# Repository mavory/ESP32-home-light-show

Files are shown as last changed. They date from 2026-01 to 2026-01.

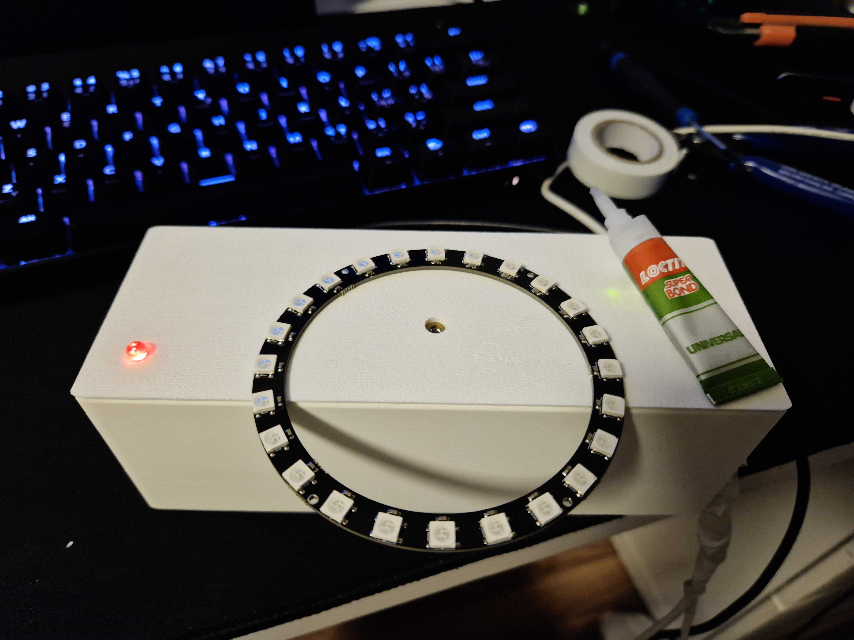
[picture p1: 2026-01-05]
Photos/IMG_20260105_200620.jpg

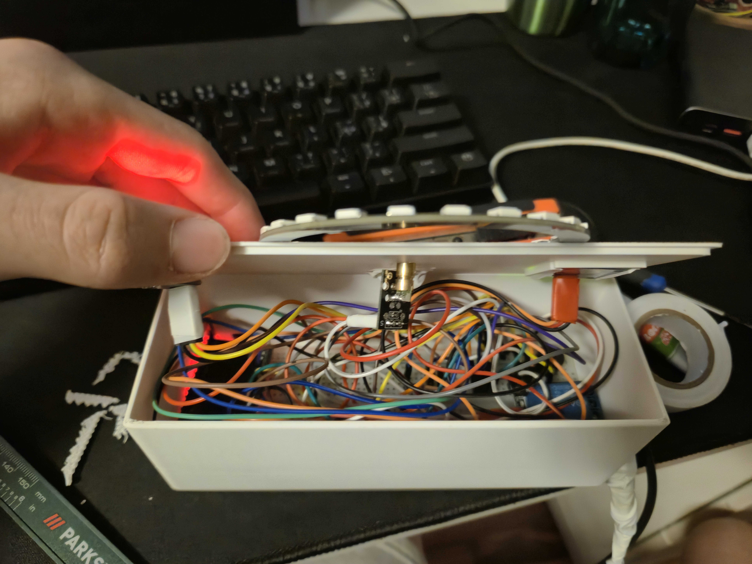
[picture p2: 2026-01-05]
Photos/20260105_195151.jpg

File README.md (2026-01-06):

# ESP32 home light show

Using ESP32 you can make a small home light show with 2 LED strips, a neopixel ring, a laser, a buzzer and an RGB LED!

## Why did I do this?

I wanted to create something with lighting effects and a few days ago I got this ring, so I wanted to try it out and also see how the relay works with LED strips.

## Features

- Web interface
- You can switch modes
- It has a buzzer and an RGB LED for notification
- You can turn off various lights, buzzer, etc.

## Scripts

The script has exactly 199 lines, so it fit under 200!! It was very difficult, but I put everything in just one script, so you can just copy it and paste it into the ESP32 right away.

## How it works?

You can change profiles and turn off various lights via the web. The web runs on the ESP32 IP address. There is a small RGB LED and a buzzer for signaling. Everything can be turned on manually using the touch sensor hidden in the case.

- **Mode 1 (FOREST):** Constant green ring light with strip.
- **Mode 2 (CYBER):** Constant magenta ring light with laser.
- **Mode 3 (NUCLEAR):** Blinking relay with orange ring and pulsing warning buzzer.
- **Mode 4 (SUNSET):** Breathing effect on the ring in sunset colors.
- **Mode 5 (AMBIENT):** White ring light and relay for steady "illumination".
- **Mode 6 (FOCUS):** Blue pulsing ring effect for concentration with active relay.
- **Mode 7 (DISCO):** Strobe for relay and laser with rainbow ring and rhythmic beeps.
- **Mode 8 (STROBE):** High speed white strobe and ring with buzzer.
- **Mode 9 (POLICE):** Red and blue flashing ring with a siren sound.
- **Mode 10 (EXTREME):** Random chaotic flashing with flickering colors and noise.

**_I like sunset the most and extreme is probably the most chaotic!_**

### Home page:


## 3D models

Here is a view of the top and bottom of the case:





# Wiring Diagram



### Components:
- **ESP32** (Powered via USB or 5V Vin)
- **Touch Sensor (TTP223):**
  - SIG: GPIO 4
  - VCC: 3.3V / 5V
  - GND: GND

### Outputs:
- **Relay (Strip Control):** GPIO 23
- **Laser Diode:** GPIO 22
- **Passive Buzzer:** GPIO 17

### Lights:
- **NeoPixel Ring (24 LEDs):**
  - Data: GPIO 21
  - VCC: 5V 
  - GND: GND
- **RGB LED:**
  - Red Pin: GPIO 19
  - Green Pin: GPIO 18
  - Blue Pin: GPIO 5
  - GND: GND
- **LED strips:**
  - 5V: COM (Relay) ---> 5V external (NO on relay)
  - GND: GND
  
# Libraries:

```
- Arduino.h
- WiFi.h
- ESPAsyncWebServer.h 
- AsyncTCP.h
- Adafruit_NeoPixel.h
- LittleFS.h
```

## There is the final video of how it works!

_Here is a youtube video where you can see how it works:_ [Link](https://www.youtube.com/watch?v=FMIBLFgBRWg)



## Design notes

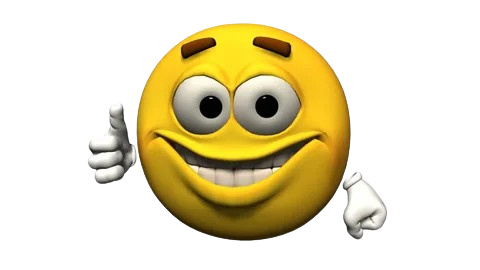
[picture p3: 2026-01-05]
Photos/1-removebg-preview.png

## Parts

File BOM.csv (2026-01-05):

Item | Quantity | Link
ESP32 | 1 | https://www.aliexpress.com/item/1005009694232832.html?curPageLogUid=bPYYmnweQOZ8
RGB led | 1 | https://www.aliexpress.com/item/32977462875.html?scm_id=1007.40050.354490.0&scm-url=1007.40050.354490.0
Touch sensor | 1 | https://www.aliexpress.com/item/1005008974368078.html?curPageLogUid=BUF3rwzADrHK
Breadboard | 1 | https://www.aliexpress.com/item/1005009799908389.html
Laser module | 1 | https://www.aliexpress.com/item/1005002823239061.html
Buzzer | 1 | https://www.aliexpress.com/item/1005006260328559.html?curPageLogUid=u9zf8d5xh8uM
Jumpers | Much | https://www.aliexpress.com/item/1005002611994443.html?curPageLogUid=fx2zB0EGcu5H
Led strips | 2 | https://www.aliexpress.com/item/1005009927754396.html?curPageLogUid=CeXHUmpYYu8P
Rele | 1 | https://www.aliexpress.com/item/1005009119776598.html?curPageLogUid=jzKWMm1aqF48
Ring module | 1 | https://www.aliexpress.com/item/1005008125328620.html

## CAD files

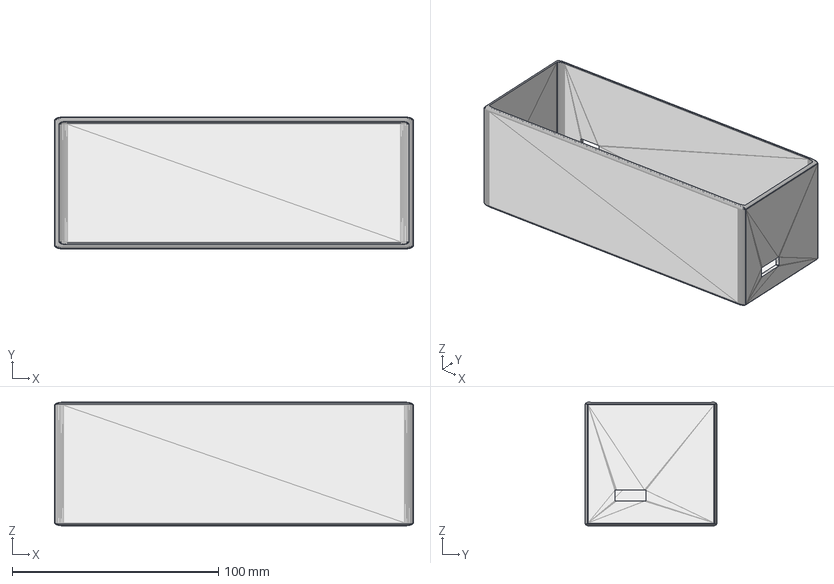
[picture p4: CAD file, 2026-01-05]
CAD/Case_bottom.step
174.0 x 64.0 x 60.0 mm

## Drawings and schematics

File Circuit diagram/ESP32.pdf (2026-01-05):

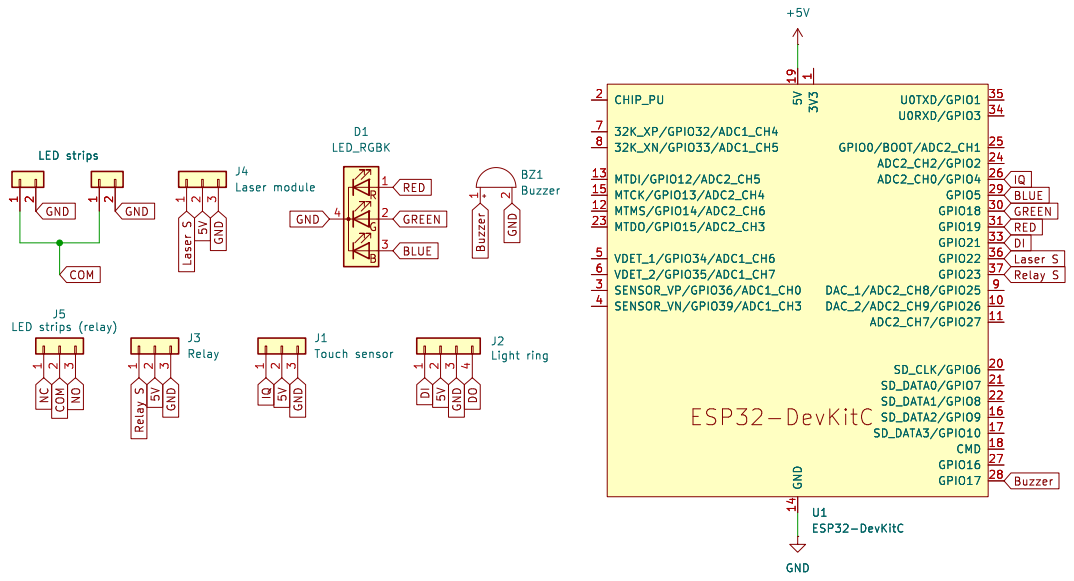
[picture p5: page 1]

1 U0TXD/GPIO1 35 U0RXD/GPIO3 34 GPIO0/BOOT/ADC2_CH1 25 ADC2_CH2/GPIO2 24 ADC2_CH0/GPIO4 26 GPIO5 29 GPIO18 30 GPIO19 31 GPIO21 33 GPIO22 36 GPIO23 37 DAC_1/ADC2_CH8/GPIO25 9 DAC_2/ADC2_CH9/GPIO26 10 ADC2_CH7/GPIO27 11 SD_CLK/GPIO6 20 SD_DATA0/GPIO7 21 SD_DATA1/GPIO8 22 SD_DATA2/GPIO9 16 SD_DATA3/GPIO10 17 CMD 18 GPIO16 27 GPIO17 28 U1ESP32-DevKitC GND Laser S Relay S GND5VIQ5V GND GND GND COM COM NCNO GND Buzzer BLUE GNDGREEN GNDDI 5VDO

File: ESP32.kicad_sch Sheet: /
Id: 1/1 Title: ESP32-home-light-show

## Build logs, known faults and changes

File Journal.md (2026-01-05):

# My Journal

This is a Journal where I describe everything about this project.

## So how much time did I spend on that?

I spent about 20 hours on this project.

## My worst hangups

- I guess.. I did the case wrong, so I had to redo it.
- I couldn't solve one bug for a long time, so it kept me very busy.
- Several times, the cables fell out of my breadboard, so I forgot where they were supposed to be connected.

## Timeline

### The beginning of an idea!
After my last project I decided to make a new one - a home light show. I was thinking about what I could do with the things I have at home and how:

The website would control everything and I could also set a scheduler, when and for how long to turn the whole system on/off.
2x LED strips that would be connected via a relay and directly to the socket
1x neopixel ring that would give that effect to it!
1x RGB LED that would signal the modes
1x buzzer so I could have a response
1x laser to add even more atmosphere
1x touch sensor that would allow everything to be controlled offline

I would like to make the website minimalistic and black and white, everything would run on the ESP32 IP address!



### Soldering cables
I was thinking about how to connect the strips to the relay and I decided to use only one, because I only have one... I put an external 5V into the COM and connected the power supply to the strips to the other one, so when it connects, the strip will light up.
But I had to solder everything and also connect everything to the jumpers first, so that everything holds well, so I took some electrical tape and wrapped it around it, because I know from before that it falls a lot, so that I could avoid that now.

Jumpers:



When I had it, as I mentioned, I started soldering, first I tinned each wire and later started soldering it together. I also added a jumper to GND to connect it to the ESP32. Later I wrapped everything with tape again and went to connect it, but I still didn't know how to connect it to the breadboard.

Soldering:



### Connecting jumpers
I managed to connect the jumpers pretty quickly and thus I was able to move on to the code! That will probably be harder, but I'll try it.
The biggest problem for me was probably the ring, because I never connected it, but I managed to do it, so it's good now.



### My first coding
I started coding, I thought it would work, but when I finished the first code, the touch button stopped working.
I made a new code with a new website, but the strips stopped working again, my solution was to connect the GND strip externally and it started working, here you can see the first attempt of the website:



### Continuing coding!!
I told myself that I would also add user profiles so I could create my own, I also implemented flashing into the strips so they would flash and I fixed the laser that was previously on and sometimes off, I also added the ability to turn different things on and off independently.



### Another website update
I wasn't happy with my website, so I put everything on the widescreen, but some things aren't working yet, but about 80% of it is. I managed to do a lot of work today and I'll continue tomorrow.

I made the system more modern and minimalistic. I added some control buttons
I modified the editor for my own profiles, where I made new buttons for presets
I also tried to make a scheduler, but unfortunately it doesn't work yet, because it doesn't turn itself off yet.



### Making a case for ESP32!
So today I overcame myself and started making designs for a 3D case, I tried different things, but then I still ended up making a larger case and putting a lid on top, which will hold all the things, there is a hole on the side for the LED strips, because those will have the case itself, which I will create later.
On the back of the case there will be power for the ESP32 and on the top there will be holes for the ring, LED,...
It took me a while today, but I think I did a good job.



### Rewriting broken code
I'm continuing with the website, unfortunately I've been coding for over 2 hours today and I still can't find the problem with the profile editor.
I probably have a long way to go, but so far I've completely redone the profile files, which I think are awesome! The buttons now work on and off. Now I'm going to start 3D printing the case and later I'll make the upper part for the case, which I still have to model.



### Error solved
I tried for about an hour, but unfortunately I couldn't figure out how to fix this error, so I removed it all, unfortunately. I focused on the code with the preset profiles and modified them.
For now, I have the code ready and now I'm going to start making the upper part of the case. Here is the description of the profiles:

Mode 1 (FOREST): Constant green ring light with strip.
Mode 2 (CYBER): Constant magenta ring light with laser.
Mode 3 (NUCLEAR): Blinking relay with orange ring and pulsing warning buzzer.
Mode 4 (SUNSET): Breathing effect on the ring in sunset colors.
Mode 5 (AMBIENT): White ring light and relay for steady "illumination".
Mode 6 (FOCUS): Blue pulsing ring effect for concentration with active relay.
Mode 7 (DISCO): Strobe for relay and laser with rainbow ring and rhythmic beeps.
Mode 8 (STROBE): High speed white strobe and ring with buzzer.
Mode 9 (POLICE): Red and blue flashing ring with a siren sound.
Mode 10 (EXTREME): Random chaotic flashing with flickering colors and noise.
I like sunset the most and extreme is probably the most chaotic!



### Finishing the 3D models!!
I think this is done. Hopefully everything will fit... I measured everything and made holes for everything.
There is a hole for the ESP32 power supply at the back and another for the LED strips.
The strips will be led away on the side.
At the top in the middle there is a hole for the laser and above that there is a hole exactly for the ring, which will be placed there later. On the right I made a holder for the touch sensor, which probably took me the most time! Then I added a hole for the LED and connected everything together. I rendered everything and it was done.





### 3D Case Remake
Ahhh... Unfortunately I modeled the top part badly. So it took away my precious time to redo it again. All the holes are too small, I thought the values would be good, but I was wrong. I also made a low slider for the touch sensor, so I redid all of that.



### Circuit Diagram is ready
I tried to create a circuit diagram in KiCad, I used ESP32 again, buzzer, RGB LED,... I connected everything, but before that I was wondering if there were different models for some components in my project - I couldn't find anything after research, so I used generic connectors.
After connecting and exporting, I remembered that I could add how I would connect the 5V strips to the relay, so I finished that and I think that it should be all from KiCad.



### Finishing the case
I decided to make the case first and then finish GitHub. I started by putting the breadboard with the components in the case and as always (it's a ritual) the cables fall out, so I don't know where to connect them...
But when I solved this, another problem came up, I couldn't get to the relay very well, but I somehow managed to connect the LED strips. The holes for the things were already big enough and everything went smoothly. I later glued the ring so that it wouldn't move.
I also had to remove the supports from the 3D print, then I closed and glued everything together!



### Finishing the smaller details
I still had to finish some minor details. I had to peel off the ring and stick it back on and tape it from the bottom. I also wrapped the cable with white tape and closed everything again later.



### GitHub editing

When I had the case finished, I spent some time working on **GitHub**. I had to export all the **stuff** and later **upload it** to the aforementioned GitHub:
- BOM
- Journal.md
- Readme.md
- CAD (3D models)
- Scripts (.ino script)
- Circuit diagram (Info.md and CD)
- Photos



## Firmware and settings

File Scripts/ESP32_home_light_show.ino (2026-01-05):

#include <Arduino.h>
#include <WiFi.h>
#include <ESPAsyncWebServer.h>
#include <Adafruit_NeoPixel.h>
#include <LittleFS.h>
//PINOUT!!!!!!
#define PIN_RELAY 23
#define PIN_LASER 22
#define PIN_RING  21
#define PIN_BUZZ  17
#define PIN_TOUCH 4
#define PIN_L_R   19
#define PIN_L_G   18
#define PIN_L_B   5
#define NUM_LEDS  24

Adafruit_NeoPixel ring(NUM_LEDS, PIN_RING, NEO_GRB + NEO_KHZ800);
AsyncWebServer server(80);//WEB SERVER

bool sysOn = false; //jestli je systen on na bootu
int currentMode = 1;
bool hwRelay = true, hwLaser = true, hwRing = true, hwBuzz = true;

const int chBuzz = 0;

void setStatusLED(int r, int g, int b) {
  digitalWrite(PIN_L_R, r);
  digitalWrite(PIN_L_G, g);
  digitalWrite(PIN_L_B, b);
}

void killBuzzer() {
  ledcWrite(chBuzz, 0);
  ledcDetachPin(PIN_BUZZ);
  pinMode(PIN_BUZZ, OUTPUT);
  digitalWrite(PIN_BUZZ, LOW);
}

void reattachBuzzer() {
  ledcSetup(chBuzz, 2000, 8);
  ledcAttachPin(PIN_BUZZ, chBuzz);
}

void stopAll() {
  killBuzzer();
  digitalWrite(PIN_RELAY, LOW);
  digitalWrite(PIN_LASER, LOW);
  ring.clear();
  ring.show();
}

void ringEffect(int type, uint32_t color, int speed, int bright) {
  if(!hwRing || !sysOn || bright == 0) { ring.clear(); ring.show(); return; }
  ring.setBrightness(bright);
  unsigned long ms = millis();
  int s = (speed < 20) ? 20 : speed;
  int pos = (ms / (s/4)) % NUM_LEDS;

  switch(type) {
    case 0: for(int i=0; i<NUM_LEDS; i++) ring.setPixelColor(i, color); break;
    case 1: ring.clear(); for(int i=0; i<6; i++) ring.setPixelColor((pos+i)%NUM_LEDS, color); break;
    case 2: for(int i=0; i<NUM_LEDS; i++) ring.setPixelColor(i, ring.ColorHSV((ms/4 + i*2730) % 65536, 255, 255)); break;
    case 3: 
      { // Přidány závorky pro vyřešení chyby "jump to case label", prostě to strašný bug
        ring.clear(); 
        int b = ( (ms/s) % (NUM_LEDS*2) < NUM_LEDS ) ? (ms/s)%NUM_LEDS : (NUM_LEDS*2 - (ms/s)%NUM_LEDS - 1); 
        ring.setPixelColor(b, color); 
      } 
      break;
    case 4: if(random(10)>7) ring.setPixelColor(random(NUM_LEDS), color); else ring.clear(); break;
  }
  ring.show();
}

void playSound(int type, int vol, int speed) {
  if(!hwBuzz || type == 0 || vol == 0 || !sysOn) { ledcWrite(chBuzz, 0); return; }
  unsigned long ms = millis();
  int freq = 0; bool on = false;
  switch(type) {
    case 1: if(ms % 1000 < 150) { freq = 2000; on = true; } break;
    case 2: freq = 800 + (sin(ms * 0.007) * 400); on = true; break;
    case 3: if(ms % speed < (speed/2)) { freq = 1000; on = true; } break;
    case 4: if(random(100) < 15) { freq = random(300, 2000); on = true; } break;
    case 5: if(ms % 100 < 50) { freq = 3000; on = true; } break;
  }
  if(on) { ledcWriteTone(chBuzz, freq); ledcWrite(chBuzz, vol); } else ledcWrite(chBuzz, 0);
}
//toto je web, prostě zase ta šibenice moje
const char index_html[] PROGMEM = R"rawliteral(
<!DOCTYPE html><html><head><meta charset="UTF-8"><meta name="viewport" content="width=device-width, initial-scale=1">
<style>
  body { background:#000; color:#fff; font-family:sans-serif; margin:0; padding:10px; }
  .panel { background:#0a0a0a; border:1px solid #222; padding:15px; border-radius:12px; max-width:500px; margin:auto; }
  .grid { display:grid; grid-template-columns:repeat(2, 1fr); gap:10px; margin-bottom:20px; }
  button { background:#151515; border:1px solid #333; color:#fff; padding:15px 5px; border-radius:8px; cursor:pointer; font-size:12px; font-weight:bold; }
  .act { background:#fff !important; color:#000 !important; }
  .pwr { width:100%; padding:20px; font-size:16px; margin-bottom:20px; border:2px solid #fff; border-radius:10px; font-weight:bold; background:none; color:#fff; }
  .poff { border-color:#f44; color:#f44; }
  .hw-grid { display:grid; grid-template-columns:repeat(4, 1fr); gap:5px; margin-top:20px; }
  .hw-grid button { font-size:9px; padding:10px 2px; }
</style></head><body>

<div class="panel">
  <button id="pwr" class="pwr" onclick="req('/t-sys')">SYSTEM LOADING...</button>
  
  <div class="grid">
    <button id="m1" onclick="req('/mode?v=1')">FOREST</button><button id="m2" onclick="req('/mode?v=2')">CYBER</button>
    <button id="m3" onclick="req('/mode?v=3')">NUCLEAR</button><button id="m4" onclick="req('/mode?v=4')">SUNSET</button>
    <button id="m5" onclick="req('/mode?v=5')">AMBIENT</button><button id="m6" onclick="req('/mode?v=6')">FOCUS</button>
    <button id="m7" onclick="req('/mode?v=7')">DISCO</button><button id="m8" onclick="req('/mode?v=8')">STROBE</button>
    <button id="m9" onclick="req('/mode?v=9')">POLICE</button><button id="m10" onclick="req('/mode?v=10')">EXTREME</button>
  </div>

  <div class="hw-grid">
    <button id="hwR" onclick="req('/hw?w=r')">STRIP</button><button id="hwL" onclick="req('/hw?w=l')">LASER</button>
    <button id="hwRi" onclick="req('/hw?w=ri')">RING</button><button id="hwB" onclick="req('/hw?w=b')">BUZZ</button>
  </div>
</div>

<script>
async function req(u){ await fetch('/api'+u); update(); }
async function update(){
  const r = await fetch('/api/stat'); const d = await r.json();
  const p=document.getElementById('pwr'); 
  p.className=d.on?'pwr':'pwr poff'; 
  p.innerText=d.on?'SYSTEM ONLINE':'SYSTEM OFFLINE';
  for(let i=1;i<=10;i++){ let b=document.getElementById('m'+i); b.className=d.m==i?'act':''; }
  document.getElementById('hwR').className=d.hr?'act':'';
  document.getElementById('hwL').className=d.hl?'act':'';
  document.getElementById('hwRi').className=d.hri?'act':'';
  document.getElementById('hwB').className=d.hb?'act':'';
}
setInterval(update, 2000); update();
</script></body></html>
)rawliteral";

void setup() {
  Serial.begin(115200);
  pinMode(PIN_RELAY, OUTPUT); pinMode(PIN_LASER, OUTPUT);
  pinMode(PIN_L_R, OUTPUT); pinMode(PIN_L_G, OUTPUT); pinMode(PIN_L_B, OUTPUT);
  pinMode(PIN_TOUCH, INPUT);
  
  reattachBuzzer();
  ring.begin(); ring.show();
  WiFi.begin("WIFI", "PASSWORD"); //HERE IS WIFI PASSWORD!!!!!!!!!

  server.on("/api/stat", HTTP_GET, [](AsyncWebServerRequest *r){
    String j="{ \"on\":"+String(sysOn)+",\"m\":"+String(currentMode)+",\"hr\":"+String(hwRelay)+",\"hl\":"+String(hwLaser)+",\"hri\":"+String(hwRing)+",\"hb\":"+String(hwBuzz)+"}";
    r->send(200, "application/json", j);
  });

  server.on("/api/t-sys", HTTP_GET, [](AsyncWebServerRequest *r){ sysOn=!sysOn; stopAll(); if(sysOn) reattachBuzzer(); r->send(200); });
  
  server.on("/api/mode", HTTP_GET, [](AsyncWebServerRequest *r){ 
    currentMode=r->getParam("v")->value().toInt(); 
    stopAll(); reattachBuzzer(); r->send(200); 
  });

  server.on("/api/hw", HTTP_GET, [](AsyncWebServerRequest *r){ 
    String w=r->getParam("w")->value(); 
    if(w=="r")hwRelay=!hwRelay; if(w=="l")hwLaser=!hwLaser; 
    if(w=="ri")hwRing=!hwRing; if(w=="b")hwBuzz=!hwBuzz;
    stopAll(); reattachBuzzer(); r->send(200); 
  });

  server.on("/", HTTP_GET, [](AsyncWebServerRequest *r){ r->send_P(200, "text/html", index_html); });
  server.begin();
}

void loop() {
  static bool lastTouch = false;
  bool touch = digitalRead(PIN_TOUCH);
  if(touch && !lastTouch) {
    sysOn = !sysOn; stopAll(); if(sysOn) reattachBuzzer();
    delay(300);
  }
  lastTouch = touch;

  if(!sysOn) { setStatusLED(1,0,0); stopAll(); return; }
  else setStatusLED(0,1,0);

  unsigned long now = millis();
  int f = 127 + 127*sin(now/800.0);
//ty mody, který jsou epicky
  switch(currentMode) {
    case 1: if(hwRelay) digitalWrite(PIN_RELAY, 1); ringEffect(0,0x00FF00,0,150); break;
    case 2: if(hwLaser) digitalWrite(PIN_LASER, 1); ringEffect(0,0xFF00FF,0,200); break;
    case 3: if(hwRelay && now%1000<500) digitalWrite(PIN_RELAY, 1); else digitalWrite(PIN_RELAY,0); ringEffect(0,0xFF6000,0,200); playSound(3,150,600); break;
    case 4: if(hwRelay) digitalWrite(PIN_RELAY, 1); ringEffect(0,ring.Color(255,f/2,0),0,f); break;
    case 5: if(hwRelay) digitalWrite(PIN_RELAY, 1); ringEffect(0,0xFFFFFF,0,150); break;
    case 6: if(hwRelay) digitalWrite(PIN_RELAY, 1); ringEffect(0,0x0000FF,0,f); break;
    case 7: if(hwRelay && now%400<200) digitalWrite(PIN_RELAY,1); else digitalWrite(PIN_RELAY,0); if(hwLaser && now%200<100) digitalWrite(PIN_LASER,1); else digitalWrite(PIN_LASER,0); ringEffect(2,0,50,200); playSound(3,180,400); break;
    case 8: if(now%120<60){ if(hwRelay) digitalWrite(PIN_RELAY,1); ringEffect(0,0xFFFFFF,0,255); } else { digitalWrite(PIN_RELAY,0); ring.clear(); } playSound(5,255,0); break;
    case 9: if(now%600<300){ ringEffect(0,0xFF0000,0,255); } else { ringEffect(0,0x0000FF,0,255); } playSound(2,180,0); break;
    case 10: if(random(10)>7 && hwRelay) digitalWrite(PIN_RELAY,1); else digitalWrite(PIN_RELAY,0); if(random(10)>6 && hwLaser) digitalWrite(PIN_LASER,1); else digitalWrite(PIN_LASER,0); ringEffect(4,ring.Color(random(255),random(255),random(255)),50,255); playSound(4,220,0); break;
  }
}

//@MAVORY WAS HERE

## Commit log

2026-01-05 Circuit diagram
2026-01-05 STEP files
    [Case_bottom.step]
